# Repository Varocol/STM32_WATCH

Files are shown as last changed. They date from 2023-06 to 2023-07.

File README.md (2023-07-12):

#  STM32 WATCH 进度表

## 进度表

- [20230709~20230712](#2023070920230712)

- [20230707~20230708](#2023070720230708)

- [20230616~20230706](#2023061620230706)

- [20230615](#20230615)

- [20230614](#20230614)

- [20221215~20230613](#2022121520230613)

### 20230709~20230712

- 串口模块测试通过
- 蜂鸣器模块测试通过

### 20230707~20230708

- 按键模块测试通过

### 20230616~20230706

- 划水摸鱼

### 20230615

- 搭建所有传感器的驱动框架和系统框架。

- 测试通过了led和delay驱动模块

### 20230614

- 使用eide插件的模板创建项目

- 调整了下载参数(SWDIO)，MCU RAM布局，编译器版本以及预编译宏定义

### 20221215~20230613

- 项目立项

- 芯片选型

- 选择所需功能的传感器

- 设计对应传感器芯片的周围电路

- 基本完成原理图的设计

- 基本完成PCB布局设计

- V1.0失败，PCB代工厂商无法完成样板打样

- V1.1打样通过，因该版本未做核心板和扩展板分离，所以测试暂时失败

- V1.2打样通过，作为方案板正在验证

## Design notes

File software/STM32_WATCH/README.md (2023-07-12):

# 模块列表

- [蜂鸣器](#蜂鸣器)

- [调试串口](#调试串口)

- [工作LED](#工作LED)

- [延时](#延时)

- [按键](#按键)

## 蜂鸣器

引脚：PA1

实现：

- 通道TIM2_CH2，pwm输出，dma连续装载，TIM1计时。TIM1的分频改为0.5ms为单位，这样不容易溢出。（考虑到dma装载以更新时间（即一次波形）为单位，所以需要使用中断累计延时总长度）。

提供数据：
- 蜂鸣器音量

功能：

- 选择提示

- 音乐

关联变量：

- beep_volume

由于使用的是TIM2，没有重复计数功能，下一代硬件会更改引脚，并使用重复计数+DMA

方案：
- systick基础延时+pwm输出（程序阻塞）
- tim定时器中断计时（计音符长度）+pwm输出（有更多时间处理动画）（目前采用的方案）
- 直接pwm输出DMA（会消耗非常大的空间，可以DMA中断片段装载）
- 高级定时器重复计数+DMA（最优方案）

## 调试串口

引脚：RX PA10 TX PA9

实现：

- 驱动USART1

功能：

-  输出调试日志

## 工作LED

引脚：PB9

实现方式：

- GPIO驱动

功能：

- 指示工作状态

- 指示充电状态

- 指示联网状态	

## 延时

实现方式：Systick

功能：

- 做基础延时

## 按键

KEY1 引脚：PA6

KEY2 引脚：PA4

KEY3 引脚：PA5

KEY4 引脚：PC13

实现方式：

- GPIO驱动

- TIM2定时器中断1ms轮询 

状态数据：

- 按键当前状态（不持续的，1ms宽度离散状态）

- 按键状态持续时间（以1ms为单位，1ms宽度离散状态）

功能：

- KEY4作为开关机按键，菜单确认按键

- KEY1 KEY2 KEY3 作为菜单功能选择按键或菜单确认按键

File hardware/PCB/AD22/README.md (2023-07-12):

# PCB版本

- [V1.3](#V13)

- [V1.2](#V12)

- [V1.1](#V11)

- [V1.0](#V10)

## V1.3

更改Buzzer引脚，使用TIM1的通道（目前不打算改用扬声器，如果想升级会考虑2.0版本弃用蜂鸣器）。

增加定位孔为手表外壳做准备。

将电池焊盘改成连接座。

## V1.2

由于上个版本的扩展板(用于测量血氧浓度)不方便裁剪，这回将扩展板和核心板做分离处理，并做了一会拼板，为下一次打样做准备。

## V1.1

这回采用的是4层结构，删掉了之前的CH340E芯片，以及STM32的自动下载电路，直接采用SWD接口调试下载，成功打样。

## V1.0 

PCB 失败，原因是由于原理图元件过多，导致整张板子虽然能排满，但是线路过于复杂，所以使用了6层板，嘉立创6层板免费券的使用要求是不能有盲孔和过孔(当然它不支持该工艺)，所以6层板打样失败，下一个版本将优化pcb布线，尽量使用4层板。

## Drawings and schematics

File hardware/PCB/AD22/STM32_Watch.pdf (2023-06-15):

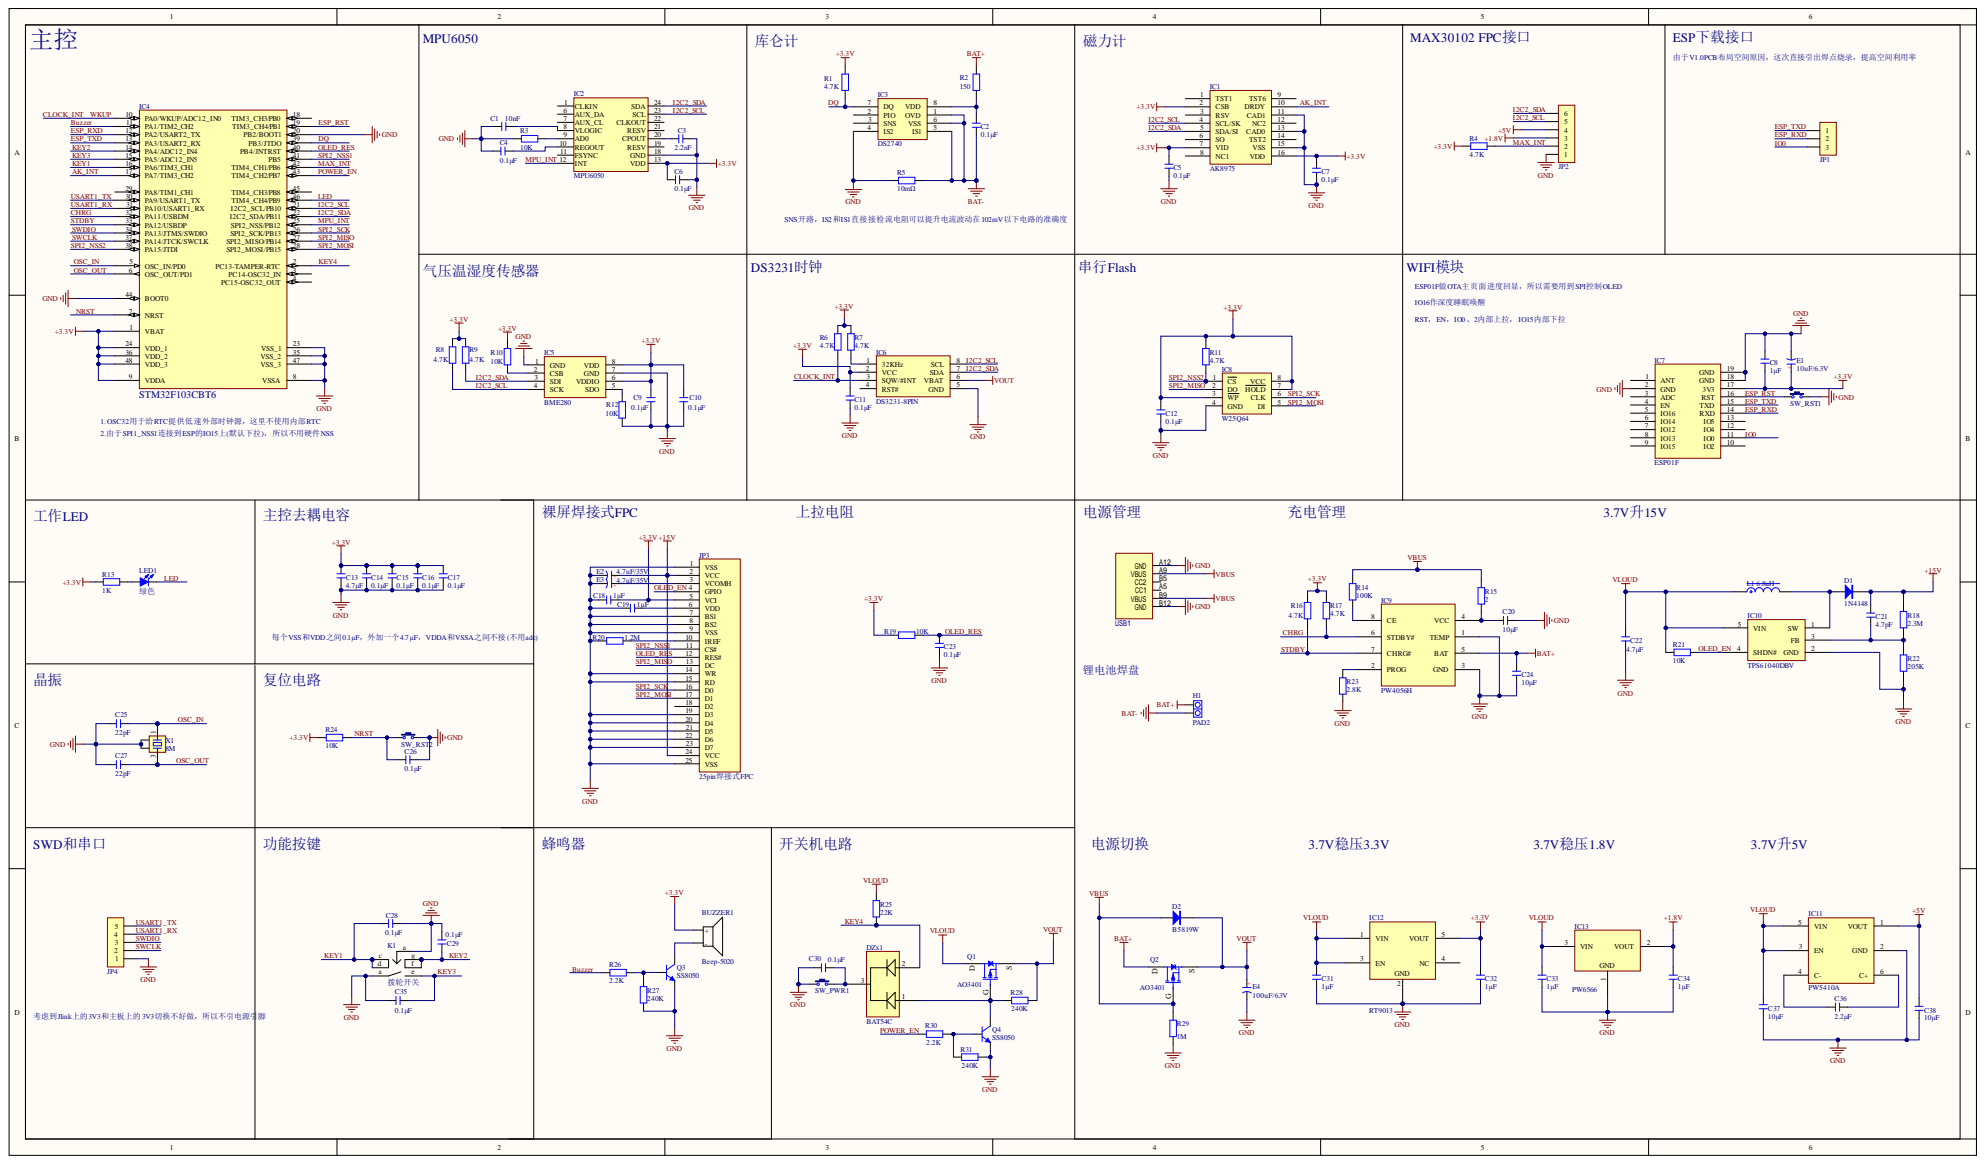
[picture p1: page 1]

IC4 | MPU6050 IC2 | 库仑计 +3.3V BAT+ IC3 | 磁力计 IC1 | MAX30102 FPC接口 | ESP下载接口 由于V1.0PCB布局空间原因，这次直接引出焊点烧录，提高空间利用率

VCOMH 3

VCI 5

SPI2_SCK | D0 16

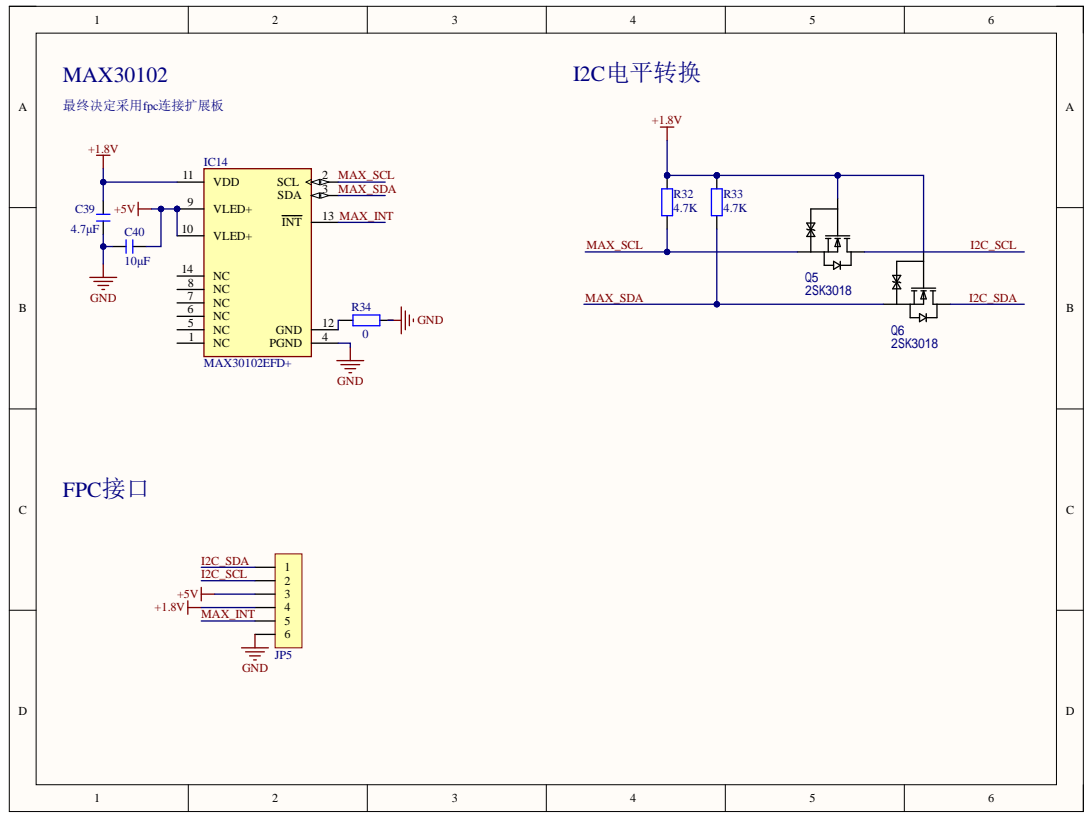
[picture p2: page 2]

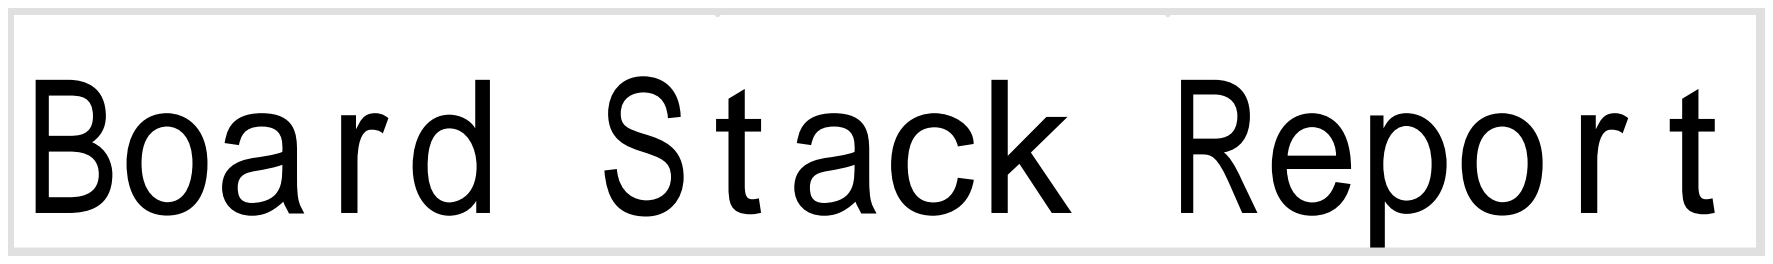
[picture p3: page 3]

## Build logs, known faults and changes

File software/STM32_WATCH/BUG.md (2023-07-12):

# 解决的BUG：

- [20230711](#20230711)
- [20230708](#20230708)

## 20230711

1.使用printf需要关闭半主机模式，否则会进入_sys_open死循环，并且需要关闭mircolib（之前碰到过就当温习一遍）

2.使用c++的库空间不够，需要调整启动文件的堆栈大小。

3.TIM定时器的TIM_Period参数可能会溢出，所以需要根据分频TIM_Prescaler来确定，将TIM1的分频调整为0.5ms后不溢出。

4.初始化全局变量的时候不要使用另一个全局变量代入，否则可能会出现另一个全局变量还未初始化导致值不对的情况（全局）

## 20230708
1.解决了将stm32f10x_it.h c/c++混合编译时导致的符号表对不上并且引发的Systick_Handler()的问题(之前也遇到过)。

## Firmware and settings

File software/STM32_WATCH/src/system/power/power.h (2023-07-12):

#pragma once
#include "delay.h"

#define pwr_port GPIOB
#define pwr_pin GPIO_Pin_7
#define pwr_rcc RCC_APB2Periph_GPIOB
#define pwr_on_delay_ms 1000

void power_on();
void power_off();

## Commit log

2023-06-15 初始化仓库
    [STM32_Watch.PrjPcb, STM32_Watch.SCHLIB, V1.0.SchDoc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]
2023-06-15 修改hardware readme
2023-07-09 key模块测试通过
    [STM32_Watch.PrjPcb]
2023-07-12 beep uart 模块测试通过，修改了文档
    [STM32_Watch.SCHLIB, V1.2-核心板.SchDoc]
